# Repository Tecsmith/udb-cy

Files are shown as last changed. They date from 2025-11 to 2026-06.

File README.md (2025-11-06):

# Unified Daughterboard CY

> Based on https://github.com/Unified-Daughterboard/UDB-C-Legacy  
> &copy; 2019 ai03

The Unified Daughterboard is an open standard to unify the USB daughterboards used in custom mechanical keyboard projects.

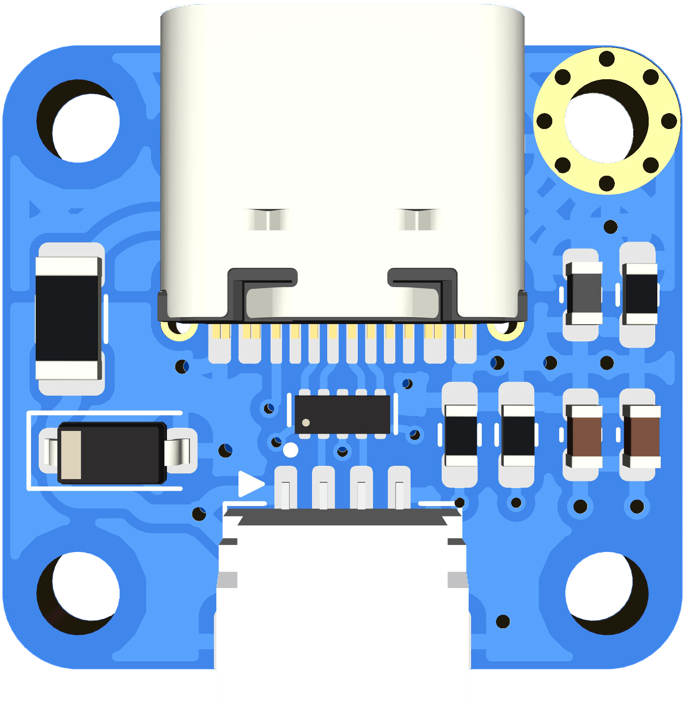
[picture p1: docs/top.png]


## This spinoff 

The UDB project has progressed to 3 distinct variants:
- C-JSH with JST PH connector
- C-EZM with Molex Pico-EZmate connector
- and a thinner variant S, also with EZmate connector

These new C5 variants has opted to merge shield grounding and cable ground, but this variant is more cautious on case/cable grounding and protects the circuit ground with a 4.7 µF capacitor and a 1 MΩ resistor that are used as a **common EMI (Electromagnetic Interference) and ESD (Electrostatic Discharge) filtering network**.

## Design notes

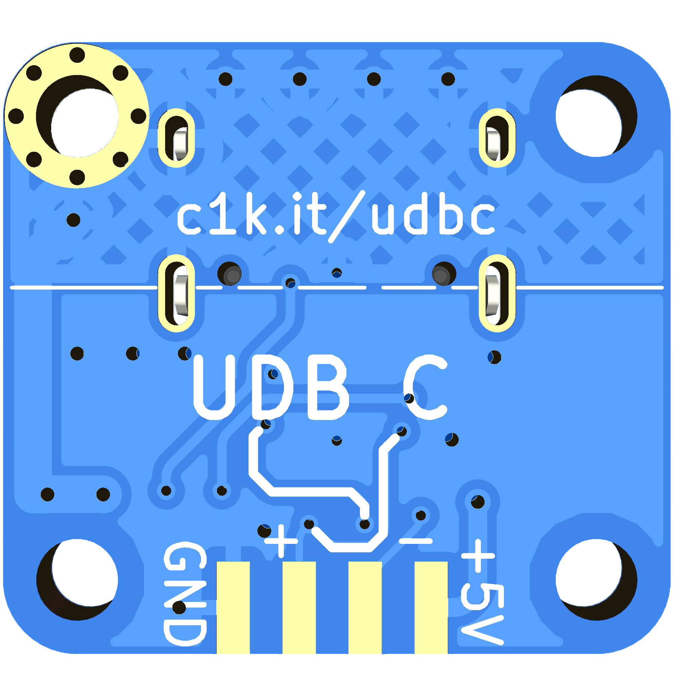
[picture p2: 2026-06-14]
docs/btm.png

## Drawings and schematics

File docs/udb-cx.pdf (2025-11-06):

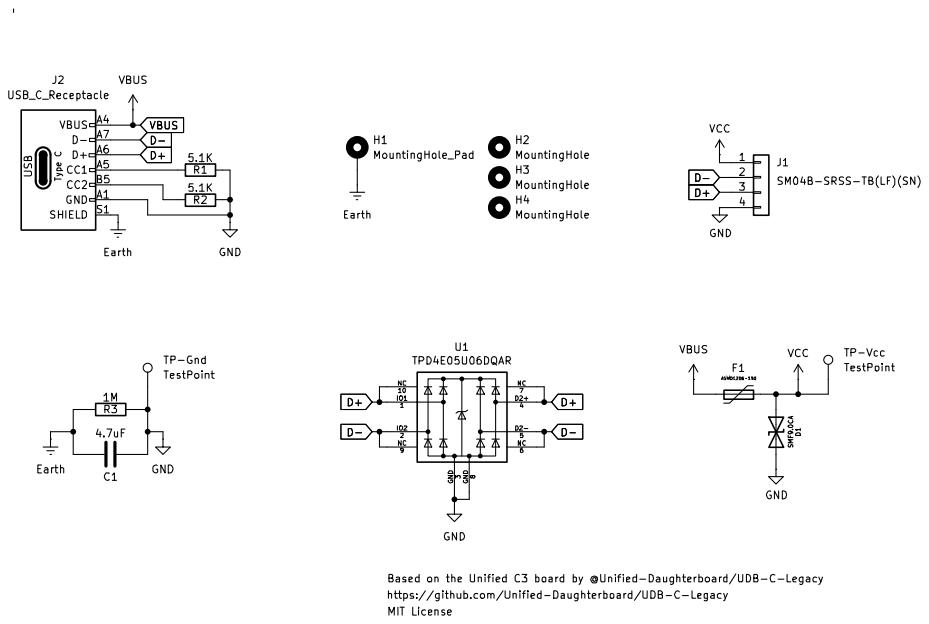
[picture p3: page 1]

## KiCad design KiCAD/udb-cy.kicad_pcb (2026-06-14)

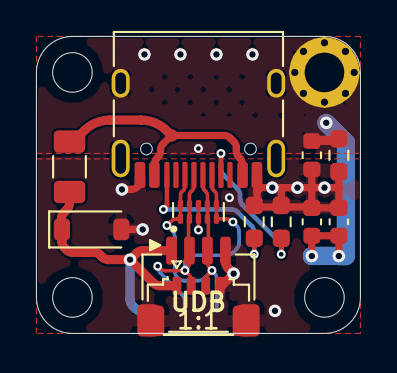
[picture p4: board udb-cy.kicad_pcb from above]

Board: 4 copper layers, 18.0 x 16.5 mm, 17 parts (1 on the bottom side), 8 nets.

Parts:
C1: 0.1µF; C_0603_1608Metric
C2: 1nF; C_0603_1608Metric
D1: SMF9.0CA; D_SOD-123
F1: ASMD1206-150; Fuse_1206_3216Metric
FB1: 600Ω @ 100MHz; L_0603_1608Metric
H1: Mount_M2_Rel
H2, H3, H4: Hole_M2
J0: USB_C_Receptacle; USB_C_Receptacle_HRO_TYPE-C-31-M-12
J1: JST-SH-04; JST_SH_SM04B-SRSS-TB_1x04-1MP_P1.00mm_Horizontal
J2: JST-SUR-04; JST_SUR_SM04B-SURS-TF_1x04-1MP_P0.80mm_Horizontal
J3: Conn_01x04; 1x04_P2.54mm_SolderPads
R1, R2: 5.1K; R_0603_1608Metric_Pad0.98x0.95mm_HandSolder
R3: 1M; R_0603_1608Metric_Pad0.98x0.95mm_HandSolder
Z1: TPD4E05U06DQAR; UFDFN-10_2.5x1.0mm_P0.5mm

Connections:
D+: J0.A6 (D+), J0.B6 (D+), J1.3, J2.3 (_3), J3.3, Z1.1, Z1.4, Z1.7, Z1.10
D-: J0.A7 (D-), J0.B7 (D-), J1.2, J2.2 (_2), J3.2, Z1.2, Z1.5, Z1.6, Z1.9
Earth: C1.1, C2.1, FB1.1, H1.MP, J0.SH (SHIELD), R3.1
GND: C1.2, C2.2, D1.2 (A2), FB1.2, J0.A1 (GND), J0.A12 (GND), J0.B1 (GND), J0.B12 (GND), J1.4, J1.MP, J2.4 (_4), J2.MP, J3.4, R1.2, R2.2, R3.2, Z1.3, Z1.8
unnamed: J0.A5 (CC1), R1.1
unnamed: J0.B5 (CC2), R2.1
VBUS: F1.1, J0.A4 (VBUS), J0.A9 (VBUS), J0.B4 (VBUS), J0.B9 (VBUS)
VCC: D1.1 (A1), F1.2, J1.1, J2.1 (_1), J3.1

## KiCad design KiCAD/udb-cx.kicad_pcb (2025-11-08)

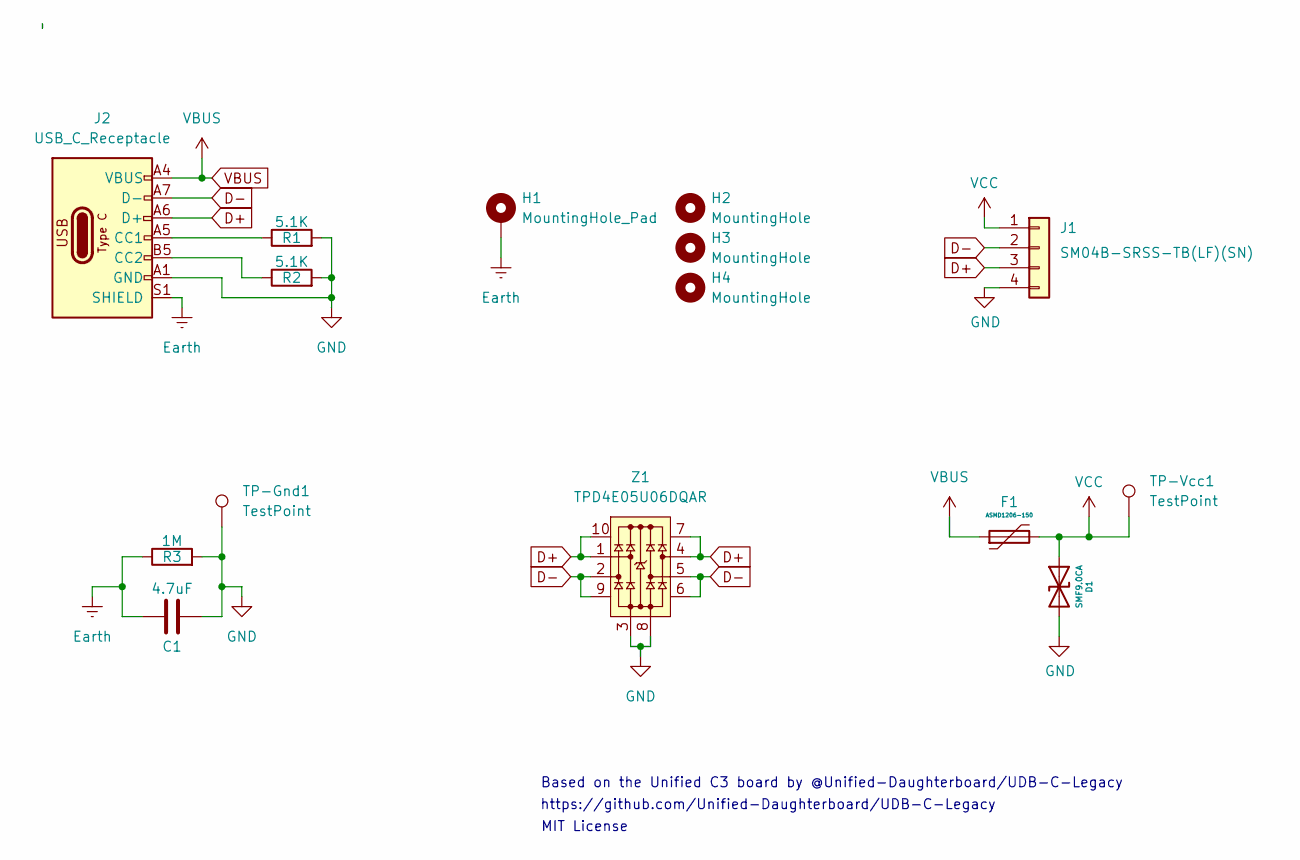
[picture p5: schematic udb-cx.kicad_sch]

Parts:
C1: 4.7uF; C_0603_1608Metric
D1: SMF9.0CA; D_SOD-123; Manufacturer Part No SMF9.0CA; LCSC Part No C123799
F1: ASMD1206-150; Fuse_1206_3216Metric; Manufacturer Part No ASMD1206-150; LCSC Part No C135342
H1: MountingHole_Pad; MountingHole_2.2mm_M2_Pad
H2, H3, H4: MountingHole; MountingHole_2.2mm_M2
J1: SM04B-SRSS-TB(LF)(SN); JST_SH_SM04B-SRSS-TB_1x04-1MP_P1.00mm_Horizontal; Manufacturer Part No SM04B-SRSS-TB(LF)(SN); LCSC Part No C160404
J2: USB_C_Receptacle; USB_C_Receptacle_HRO_TYPE-C-31-M-12
R1, R2: 5.1K; R_0603
R3: 1M; R_0603
TP-Gnd1: TestPoint; TestPoint_Pad_1.5x1.5mm
TP-Vcc1: TestPoint; TestPoint_Pad_1.5x1.5mm
Z1: TPD4E05U06DQAR; UFDFN-10_2.5x1.0mm_P0.5mm

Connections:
D+: J1.3, J2.A6 (D+), J2.B6 (D+), Z1.1, Z1.4, Z1.7, Z1.10
D-: J1.2, J2.A7 (D-), J2.B7 (D-), Z1.2, Z1.5, Z1.6, Z1.9
Earth: C1.1, H1.1, J2.S1 (SHIELD), R3.1
GND: C1.2, D1.2 (A2), J1.4, J1.MP, J2.A1 (GND), J2.A12 (GND), J2.B1 (GND), J2.B12 (GND), R1.2, R2.2, R3.2, TP-Gnd1.1, Z1.3, Z1.8
unnamed: J2.A5 (CC1), R1.1
unnamed: J2.B5 (CC2), R2.1
VBUS: F1.1, J2.A4 (VBUS), J2.A9 (VBUS), J2.B4 (VBUS), J2.B9 (VBUS)
VCC: D1.1 (A1), F1.2, J1.1, TP-Vcc1.1

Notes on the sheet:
MIT License
Based on the Unified C3 board by @Unified-Daughterboard/UDB-C-Legacy
https://github.com/Unified-Daughterboard/UDB-C-Legacy

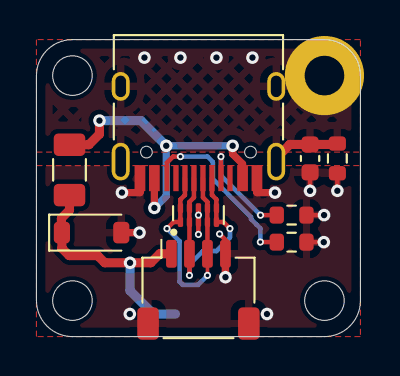
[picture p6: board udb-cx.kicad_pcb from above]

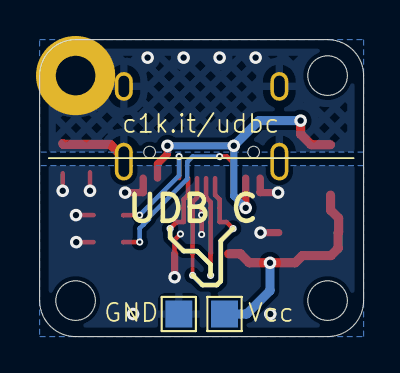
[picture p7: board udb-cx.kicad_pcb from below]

Board: 4 copper layers, 18.0 x 16.5 mm, 15 parts (2 on the bottom side), 8 nets.

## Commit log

2025-11-06 fist upload
    [udb-cx.kicad_pcb, udb-cx.kicad_sch]
2025-11-08 mil sized traces
    [udb-cx.kicad_pcb]
2025-11-10 Added JST SUR connector option
    [udb-cy.kicad_pcb, udb-cy.kicad_sch]
2025-11-14 Expose all 4 pins on the underside
    [udb-cy.kicad_pcb, udb-cy.kicad_sch]
